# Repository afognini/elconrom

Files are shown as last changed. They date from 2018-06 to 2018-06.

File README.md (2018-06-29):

# ElConRoM

**El**ectronically**Con**trolled**Ro**tation**M**ount. The objective of this project was to build an easy to use, accurate, and inexpensive rotation mount for waveplates to be used in quantum tomography experiments.

# Full Documentation

Read the file ElConRoM.pdf. The documentation is also available in docs/_build/ . The documentation can be generated by executing the command 'make latexpdf' in the folder docs/.

# How to Cite

If you use this project in your research, please consider citing it like:

Andreas Fognini ElConRoM. Available at https://github.com/afognini/.

# Authors, Copyright, License

Authors: Andreas Fognini

Copyright (C) Andreas Fognini

Released under the terms of the GPLv3 License (see file LICENSE)

# Acknowledgement

A. Fognini greatly acknowledges the support from the Swiss National Science
Foundation's Early Postdoc Fellowship.

# Requirements

Please note that this library needs Python 3.

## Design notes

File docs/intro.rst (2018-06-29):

***************
Introduction
***************

ElConRoM stands for **El**\ ectronically\ **Con**\ trolled\ **Ro**\ tation\ **M**\ ount. The objective of this project was to build an easy to use, accurate, and inexpensive rotation mount for waveplates to be used in quantum tomography experiments. This has been achieved by assembling a hollow core motor from PCBMotors in a 3D printed housing. We used the 22 mm free center motor with 5760 counts per revolution. The motor is controlled with a Python library.

This manual describes in detail how to assemble the 3D printed housing and the code to control the motor.

.. _fig_render_parts:
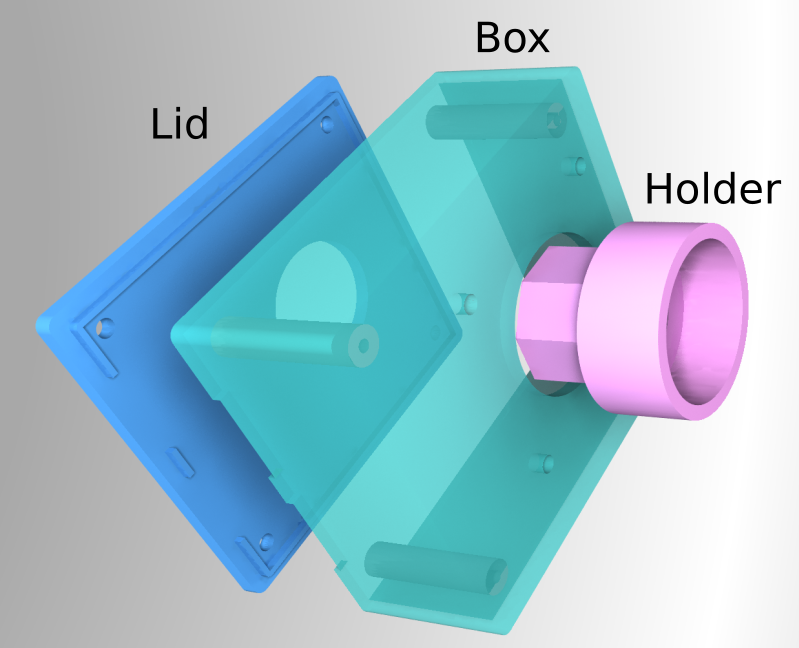
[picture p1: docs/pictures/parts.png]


    Rendered image of the three parts of the housing; the lid, the box, and the holder.

***********************************
Manufacturing the Motor Housing
***********************************
:numref:`fig_render_parts` shows a rendering of the three parts which from the motor housing - the lid, the box, and the waveplate holder.

To allow barrier free access to the CAD file the program FreeCAD_ has been used to design the parts.
All 3D parts were printed in PLA but the choice of material is not critical.
To build this project you will need the following tools/parts:

.. _FreeCAD: www.freecadweb.org

Tool/Part list
================================

To build the ElConRoM project the following tools/parts are necessary:

* 3D printer or printed parts
* A hollow core motor from www.PCBmotor.com (22 mm free center motor with 5760 counts per revolution)
* cutter knife
* 3 mm tap
* 2.5 mm, 3.5 mm, and a 6.5 mm drill
* three M3 set screws

The housing
=================================
The housing can be made in three easy steps:

* 3D print the lid (/CAD/Lid.stl) and the box (/Cad/Box.stl) and clean the edges with a cutter knife.
* The four stands of the box are drilled with 2.5 mm and tapped to hold M3 screws.
* A hole can be drilled in the side of the box to mount an optical post.

After all that preparation work we are ready to assemble the motor in its new housing.
The motor can be mounted easily in the box by removing its four screws and screwing long ones back in through the four holes next to the main optical opening of the box.
Then, the lid is mounted and the assembly of the housing is finished.

The waveplate holder
=============================

The waveplate holder or referred later as holder is manufactured in two steps:

* 3D print the holder (/CAD/Holder.stl) with 100% filling and clean the edges with a cutter knife.
* Make three M3 taps radially and equally spaced into the holding ring. These taps will later be used by three setscrews to hold the waveplate in place, compare :numref:`fig_housing` where two of the three setscrews are clearly visible.

The waveplate holder is mounted to the motor by a press fit. To scope with low tolerances from 3D printed parts, the holder which will be pressed into the motor is not round, but has an octagonal shape to have only eight well defined supporting points. Now we will discuss the fitting procedure to prepare the holder for mounting:

With a cutter knife the edges of the octagon are slightly conically reduced. In this way, the waveplate holder can be easily put into the motor and by a light press will hold within the motor's bearing. Care is necessary here to not overbend the springs within the motor.
:numref:`fig_housing` shows a picture of the assembled motor housing.

After the waveplate holder is mounted in the motor, the waveplate can be mounted in the holder by adjusting the three setscrews.

.. _fig_housing:
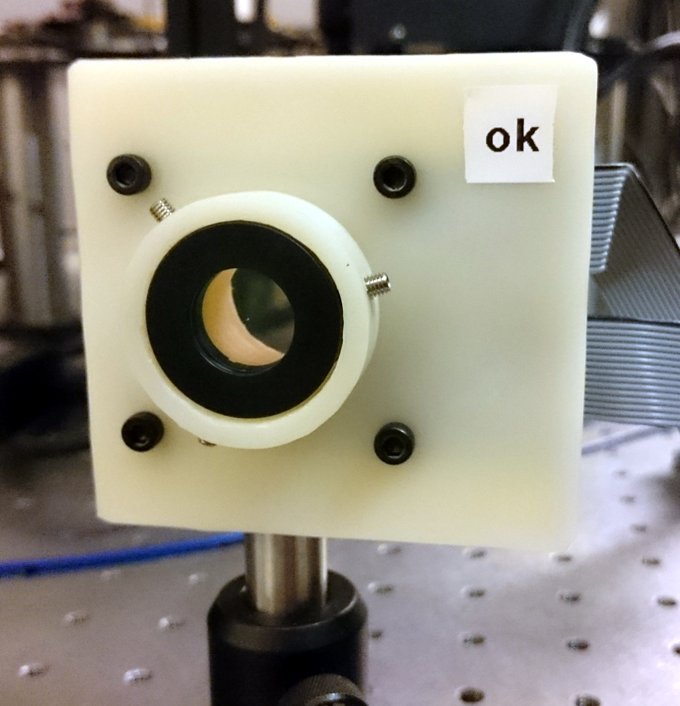
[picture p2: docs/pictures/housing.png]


    A picture of the assembled housing. The holder is equipped with a waveplate. Two of the three setscrews are clearly visible.

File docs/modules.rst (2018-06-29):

Modules Description
=========================

In the following the ElConRoM module is described.
It consists of one classe::

	* ELConRoM

This class controlles the motor.

.. toctree::
   :maxdepth: 4

ElConRoM module
-----------------------

.. automodule:: elconrom
    :members:
    :undoc-members:
    :show-inheritance:

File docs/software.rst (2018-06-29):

Usage of the ElConRoM library
==============================

The usage of the ElConRoM library is outlined in an example of moving motor 1.

.. code-block:: python

  from elconrom import ElConRoM
  import time

  motor = ElConRoM()

  #Select motor number 1
  motor.number(1)

  #Home motor
  motor.home()

  #Set it to 90 degrees
  motor.abs_position_degrees(90)

  #Wait one second
  time.sleep(1)

  #Drive back to zero degrees
  motor.abs_position_degrees(0)

It can be necessary to reduce the speed to reach more accurate stopping behavior. For example:

.. code-block:: python

  motor.speed(70)

Installation
===================

The ElConRoM Python library can be installed by the provided setup script.

You can install it either by::

	sudo python setup.py install

or by::

	sudo python3 setup.py install

depending on your Python installation. Note, ElConRoM needs Python 3 or higher.

You can test if the installation worked by importing the library:

.. code-block:: python

	import elconrom

If that did not give you an error the installation worked successfully.

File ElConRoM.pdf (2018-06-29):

# ElConRoM Documentation

# Release 1.0

# Andreas Fognini

### Jun 29, 2018

## CONTENTS

1 Introduction | 1
2 Manufacturing the Motor Housing | 3
3 Usage of the ElConRoM library | 5
4 Installation | 7
5 Modules Description | 9
6 Licenses | 11
Index | 13

i

ii

CHAPTER

## ONE

## INTRODUCTION

ElConRoM stands for ElectronicallyControlledRotationMount. The objective of this project was to build an easy to use, accurate, and inexpensive rotation mount for waveplates to be used in quantum tomography experiments. This has been achieved by assembling a hollow core motor from PCBMotors in a 3D printed housing. We used the 22 mm free center motor with 5760 counts per revolution. The motor is controlled with a Python library.

This manual describes in detail how to assemble the 3D printed housing and the code to control the motor.


Figure 1.1: Rendered image of the three parts of the housing; the lid, the box, and the holder.

1

ElConRoM Documentation, Release 1.0

### 2 Chapter 1. Introduction

CHAPTER

## TWO

## MANUFACTURING THE MOTOR HOUSING

Figure 1.1 shows a rendering of the three parts which from the motor housing - the lid, the box, and the waveplate holder.

To allow barrier free access to the CAD file the program FreeCAD has been used to design the parts. All 3D parts were printed in PLA but the choice of material is not critical. To build this project you will need the following tools/parts:

## 2.1 Tool/Part list

To build the ElConRoM project the following tools/parts are necessary:

- 3D printer or printed parts
- A hollow core motor from www.PCBmotor.com (22 mm free center motor with 5760 counts per revolution)
- cutter knife
- 3 mm tap
- 2.5 mm, 3.5 mm, and a 6.5 mm drill
- three M3 set screws

## 2.2 The housing

The housing can be made in three easy steps:

- 3D print the lid (/CAD/Lid.stl) and the box (/Cad/Box.stl) and clean the edges with a cutter knife.
- The four stands of the box are drilled with 2.5 mm and tapped to hold M3 screws.
- A hole can be drilled in the side of the box to mount an optical post.

After all that preparation work we are ready to assemble the motor in its new housing. The motor can be mounted easily in the box by removing its four screws and screwing long ones back in through the four holes next to the main optical opening of the box. Then, the lid is mounted and the assembly of the housing is finished.

## 2.3 The waveplate holder

The waveplate holder or referred later as holder is manufactured in two steps:

- 3D print the holder (/CAD/Holder.stl) with 100% filling and clean the edges with a cutter knife.
- Make three M3 taps radially and equally spaced into the holding ring. These taps will later be used by three setscrews to hold the waveplate in place, compare Figure 2.1 where two of the three setscrews are clearly visible.

3

ElConRoM Documentation, Release 1.0

The waveplate holder is mounted to the motor by a press fit. To scope with low tolerances from 3D printed parts, the holder which will be pressed into the motor is not round, but has an octagonal shape to have only eight well defined supporting points. Now we will discuss the fitting procedure to prepare the holder for mounting:

With a cutter knife the edges of the octagon are slightly conically reduced. In this way, the waveplate holder can be easily put into the motor and by a light press will hold within the motor’s bearing. Care is necessary here to not overbend the springs within the motor. Figure 2.1 shows a picture of the assembled motor housing.

After the waveplate holder is mounted in the motor, the waveplate can be mounted in the holder by adjusting the three setscrews.


Figure 2.1: A picture of the assembled housing. The holder is equipped with a waveplate. Two of the three setscrews are clearly visible.

### 4 Chapter 2. Manufacturing the Motor Housing

CHAPTER

## THREE

## USAGE OF THE ELCONROM LIBRARY

The usage of the ElConRoM library is outlined in an example of moving motor 1.

from elconrom import ElConRoM
import time

motor = ElConRoM()

#Select motor number 1

motor.number(1)

#Home motor

motor.home()

#Set it to 90 degrees

motor.abs_position_degrees(90)

#Wait one second

time.sleep(1)

#Drive back to zero degrees

motor.abs_position_degrees(0)

It can be necessary to reduce the speed to reach more accurate stopping behavior. For example:

motor.speed(70)

5

ElConRoM Documentation, Release 1.0

### 6 Chapter 3. Usage of the ElConRoM library

CHAPTER

## FOUR

## INSTALLATION

The ElConRoM Python library can be installed by the provided setup script.

You can install it either by:

sudo python setup.py install

or by:

sudo python3 setup.py install

depending on your Python installation. Note, ElConRoM needs Python 3 or higher.

You can test if the installation worked by importing the library:

import elconrom

If that did not give you an error the installation worked successfully.

7

ElConRoM Documentation, Release 1.0

### 8 Chapter 4. Installation

CHAPTER

## FIVE

## MODULES DESCRIPTION

In the following the ElConRoM module is described. It consists of one classe:

* ELConRoM

This class controlles the motor.

## 5.1 ElConRoM module

class elconrom.ElConRoM(com_port=’/dev/ttyUSB0’)
Bases: object

Implements an interface to communicate with the PCBMotor controller.

Parameters com_port (string) – Serial communcation port path.

abs_position_degrees(s)
Move to absolute position in degrees.

Parameters s (float) – Position in degrees.

abs_position_steps(s)
Move to absolute position in units of steps.

Parameters s (float) – Position in steps. Is rounded to integer while processing.

degrees_to_steps(d)
Convert degrees to steps.

Parameters d (float) – Number of degrees.

Returns Number of steps.

Return type float

home()
Home motor. Homes the motor by finding the home marker. Sets this position to zero.

number(m=1)
Select motor to address.

One controller can controll several motors. By stating the number a specific motor is selected. Note: Counting starts at 1.

Parameters m (int) – The Motor’s number which should be controlled.

query_position()
Query position.

The position is not queried from the controller but from bookkeeping of the sent steps. Therefore, not to accurate.

Returns The absolute position in steps.

9

ElConRoM Documentation, Release 1.0

Rtyep float

rel_position(s)
Move relative in units of steps.

Parameters s (float) – Number of steps. Converted to integer in function.

send(cmd)
Send the commands to the controller. Sends the commands and receives the controller’s reply which is returned.

Parameters cmd (string) – Command for the PCBMotors

Returns Reply from the motor controller.

Return type string

speed(scale)
Set speed.

The speed of clock and counter clockwise rotation is adjusted to the same value.

Parameters scale (int) – 0..255

steps_to_degrees(s)
Convert steps to degrees.

Parameters s (float) – Number of steps.

Returns Number of degrees.

Return type float

verbocity(state)
Set verbocity.

Parameters state (bool) – Verbocity active when True.

### 10 Chapter 5. Modules Description

CHAPTER

## SIX

## LICENSES

## 6.1 Source Code

The source code of the ElConRoM library is licensed under GPLv3:

Copyright (C) 2018 Andreas Fognini

This program is free software: you can redistribute it and/or modify it under the terms of the GNU General Public License as published by the Free Software Foundation, either version 3 of the License, or (at your option) any later version.

This program is distributed in the hope that it will be useful, but WITHOUT ANY WARRANTY; without even the implied warranty of MERCHANTABILITY or FITNESS FOR A PARTICULAR PURPOSE. See the GNU General Public License for more details.

You should have received a copy of the GNU General Public License along with this program. If not, see <http: //www.gnu.org/licenses/>.

## 6.2 Documentation

This documentation is licensed under the Creative Commons Attribution-ShareAlike 4.0 International License. (http://creativecommons.org/licenses/by-sa/4.0/)

11

ElConRoM Documentation, Release 1.0

### 12 Chapter 6. Licenses

## INDEX

A

abs_position_degrees() | (elconrom.ElConRoM
method), 9
abs_position_steps() (elconrom.ElConRoM method), 9
D

degrees_to_steps() (elconrom.ElConRoM method), 9
E

ElConRoM (class in elconrom), 9
elconrom (module), 9
H

home() (elconrom.ElConRoM method), 9
N

number() (elconrom.ElConRoM method), 9
Q

query_position() (elconrom.ElConRoM method), 9
R

rel_position() (elconrom.ElConRoM method), 10
S

send() (elconrom.ElConRoM method), 10
speed() (elconrom.ElConRoM method), 10 steps_to_degrees() (elconrom.ElConRoM method), 10
V

verbocity() (elconrom.ElConRoM method), 10

13

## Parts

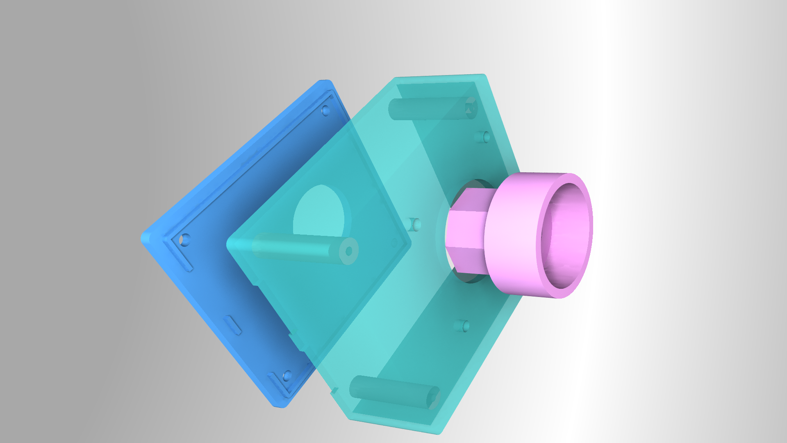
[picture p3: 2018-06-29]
docs/pictures/parts_orig.png

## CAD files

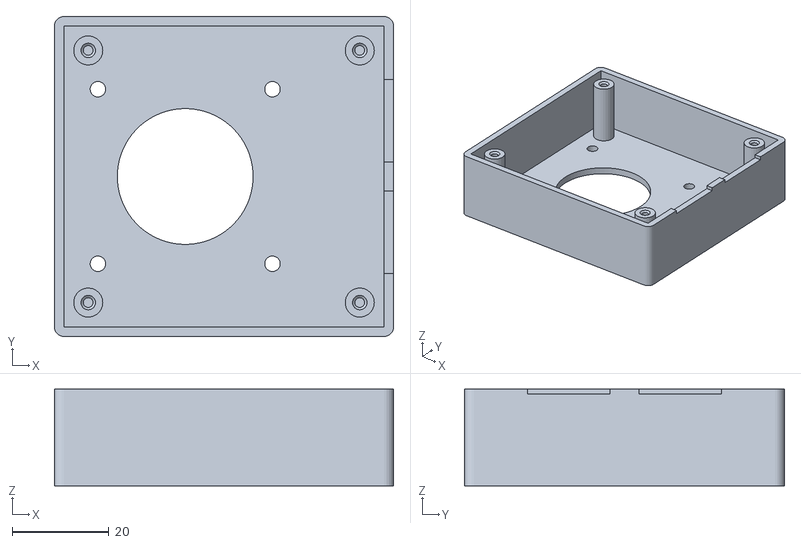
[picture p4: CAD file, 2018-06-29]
CAD/Box.stl
70.0 x 66.0 x 20.0

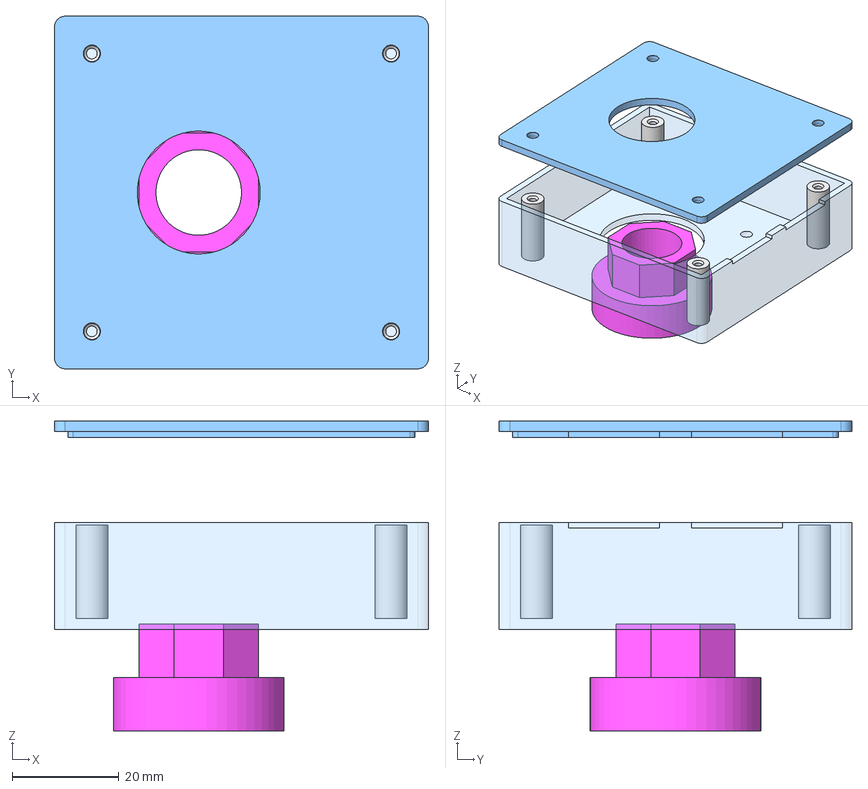
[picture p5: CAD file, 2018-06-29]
CAD/Housing.FCStd
70.0 x 66.0 x 58.0 mm
Holder

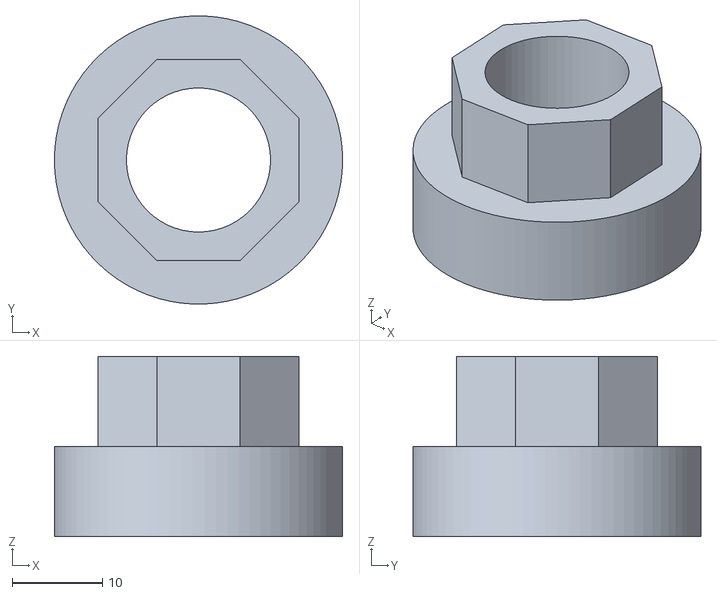
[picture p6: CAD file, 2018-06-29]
CAD/Holder.stl
32.0 x 32.0 x 20.0

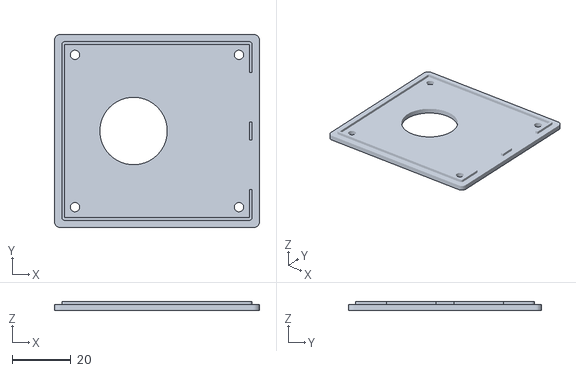
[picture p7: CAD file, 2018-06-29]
CAD/Lid.stl
70.0 x 66.0 x 3.10

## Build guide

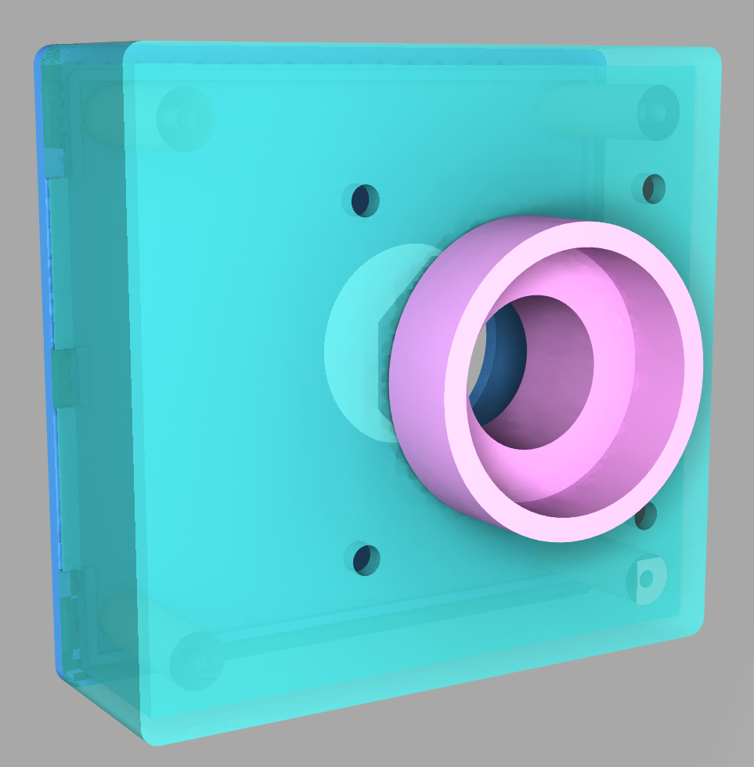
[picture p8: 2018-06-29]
docs/pictures/assembled_cut.png

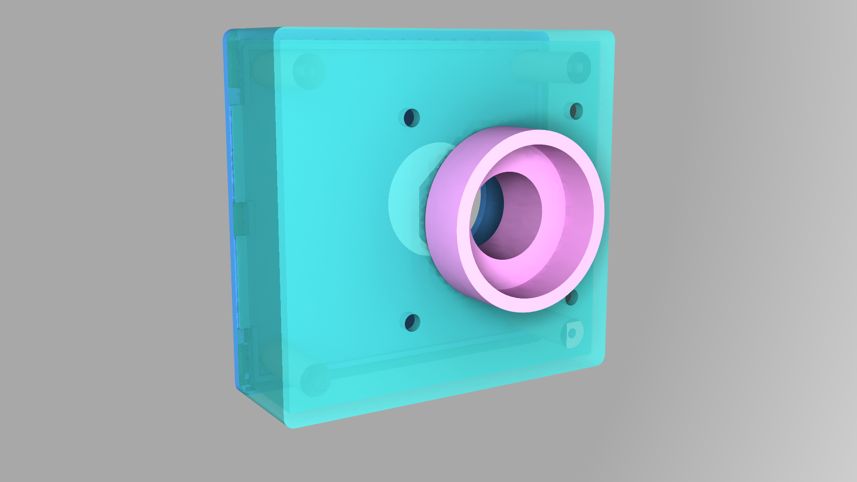
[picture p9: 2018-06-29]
docs/pictures/assembled.png

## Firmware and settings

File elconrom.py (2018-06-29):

#!/usr/local/bin/python
# -*- coding: utf-8 -*-

#Copyright (C) 2018 Andreas Fognini
#
#This program is free software: you can redistribute it and/or modify
#it under the terms of the GNU General Public License as published by
#the Free Software Foundation, either version 3 of the License, or
#(at your option) any later version.
#
#This program is distributed in the hope that it will be useful,
#but WITHOUT ANY WARRANTY; without even the implied warranty of
#MERCHANTABILITY or FITNESS FOR A PARTICULAR PURPOSE.  See the
#GNU General Public License for more details.
#
#You should have received a copy of the GNU General Public License
#along with this program.  If not, see <https://www.gnu.org/licenses/>.

#This code is implemented for python 3

import serial
import time
import random

class ElConRoM(object):
    """Implements an interface to communicate with the PCBMotor controller.

    :param string com_port: Serial communcation port path.
    """
    def __init__(self, com_port='/dev/ttyUSB0'):
        self.ENCODER_STEPS_PER_REVENUE = 5760
        self.ser = serial.Serial(port=com_port, baudrate=19200, timeout=1)
        self.motor_nbr = 1
        self._position_in_steps = 0.0

    def send(self, cmd):
        """Send the commands to the controller.
        Sends the commands and receives the controller's reply which is returned.

        :param string cmd: Command for the PCBMotors

        :return:
            Reply from the motor controller.

        :rtype: string
        """
        self.ser.flushInput()
        self.ser.write((cmd+'\r').encode())
        self.ser.flush()
        s = ""
        while True:
            s += self.ser.read().decode("utf-8")
            if ">>" in s:
                break
        return s

    def abs_position_steps(self, s):
        """Move to absolute position in units of steps.

        :param float s: Position in steps. Is rounded to integer while processing.
        """

        self.send("g"+str(int(s)))
        self._position_in_steps =+ s

    def abs_position_degrees(self, s):
        """Move to absolute position in degrees.

        :param float s: Position in degrees.
        """
        steps = int(s/360.0*self.ENCODER_STEPS_PER_REVENUE)
        self.send("g"+str(steps))
        self._position_in_steps =+ steps

    def steps_to_degrees(self, s):
        """Convert steps to degrees.

        :param float s: Number of steps.

        :return:
            Number of degrees.
        :rtype: float
        """
        return s/float(self.ENCODER_STEPS_PER_REVENUE)*360.0

    def degrees_to_steps(self, d):
        """Convert degrees to steps.

        :param float d: Number of degrees.

        :return:
            Number of steps.

        :rtype: float
        """
        return d/360.0*float(self.ENCODER_STEPS_PER_REVENUE)

    def rel_position(self, s):
        """Move relative in units of steps.

        :param float s: Number of steps. Converted to integer in function.
        """

        self.send("s"+str(int(s)))
        self._position_in_steps += s

    def query_position(self):
        """Query position.

        The position is not queried from the controller but from bookkeeping of the sent steps.
        Therefore, not to accurate.

        :return:
            The absolute position in steps.

        :rtyep: float
        """
        pos = self._position_in_steps
        return pos

    def speed(self, scale):
        """Set speed.

        The speed of clock and counter clockwise rotation is adjusted to the same value.

        :param int scale: 0..255
        """

        #Clockwise speed
        self.send("cw"+str(int(scale)))

        #Counter clockwise speed
        self.send("ccw"+str(int(scale)))

    def number(self, m=1):
        """
        Select motor to address.

        One controller can controll several motors. By stating the number a specific motor is selected. Note: Counting starts at 1.

        :param int m: The Motor's number which should be controlled.
        """

        self.motor_nbr = m
        self.send("m"+str(int(m)))

    def home(self):
        """Home motor.
        Homes the motor by finding the home marker. Sets this position to zero.
        """
        self.send('bi,bcr,z')
        self._position_in_steps=0

    def verbocity(self, state):
        """Set verbocity.

        :param bool state: Verbocity active when True.
        """
        if state:
            self.send("q-")
        else:
            self.send("q+")


if __name__ =="__main__":
    #Simple example of moving motor 1 to random postions.
    motor = ElConRoM()
    motor.verbocity(False)
    motor.number(1)

    motor.home()

    for i in range(1000):
        steps=int((random.random())*5000/2.0)
        motor.abs_position_steps(steps)
        motor.abs_position_steps(0)
        time.sleep(1)
